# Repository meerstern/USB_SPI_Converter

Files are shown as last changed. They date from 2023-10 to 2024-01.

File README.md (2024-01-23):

# USB-SPI変換基板
USB SPI Converter with MCP2210
## 概要
  * USBをSPIマスタに変換する基板です
  * デバイスの動作確認やラピッドプロトタイピングに最適です
  * [MCP2210][1]を用いたUSB-SPI変換アダプタです
  * PMOD互換コネクタを搭載しており、SPIデバイスに簡単に接続可能です
  * VCC/信号電圧はスイッチ切替で5V/3.3V切替に対応しています  
    ※3.3V専用デバイスに5Vを加えないように注意してください
    
## 詳細
 *  MCP2210はHID標準デバイスとして認識されるため、ドライバは不要です
 *  MCP2210の仕様についてはデータシートを参照してください
 *  9つのGPIO及び1つのSPIポートが利用可能です
 *  SPIクロック速度は1.5k~ 12Mbpsまで対応しています
 *  全SPIモード(Mode 0, 1, 2, 3)に対応しています
 *  64byteの送受信バッファを搭載しています
 *  1回の送受信は最大65535byteまで対応しています
 *  HIDデバイスとして認識される仕様上、最大転送レートは64kByte/sec程度となります  
 *  COM-LEDはIO3に接続されています
 *  基板上のSPI Flashパターンを介して書き込む場合はIO0とIO2をhighに設定してください  
 *  USB5V電源入力側に350mA定格のリセッタブルヒューズを搭載しています  
 *  給電可能な電流は3.3Vラインで最大150mA前後、5Vラインで最大350mAです  

## サンプル例
 * MCP2210 Utility  
 [Microchip社MCP2210 Utility][2]からGUIでSPI通信をすることが可能です
 * Web USB SPI  
 Web USB HID APIを用いた[ツールでブラウザから操作するアプリ][3]です。オフラインでも動作可能です。
 * Web USB SPI Flash Tool  
 Web USB HID APIを用いた[ツールでブラウザからSPI Flashの読込/書込するアプリ][4]です。オフラインでも動作可能です。

## ピンアサイン
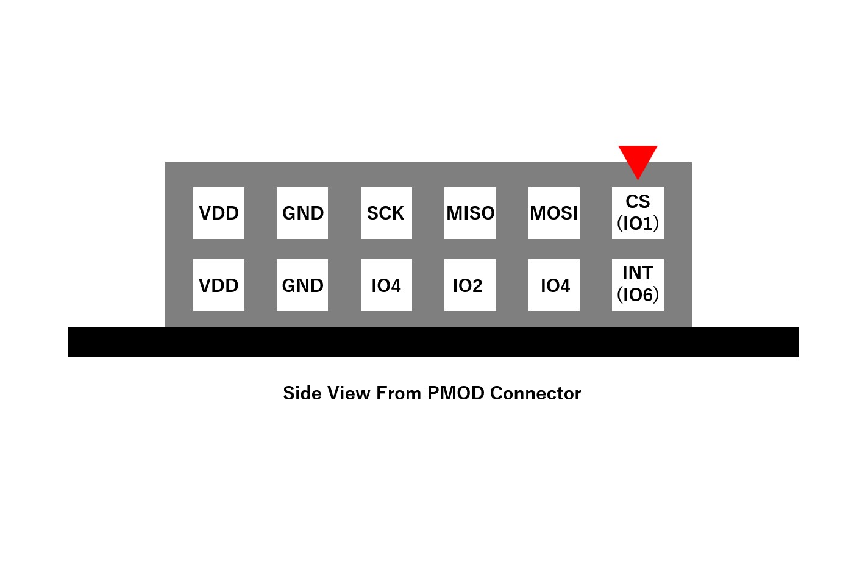
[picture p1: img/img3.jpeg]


## 外観
 * 基板サイズ45mm x 25mm(突起部除く)
 * 固定穴M3x2、幅19mm 
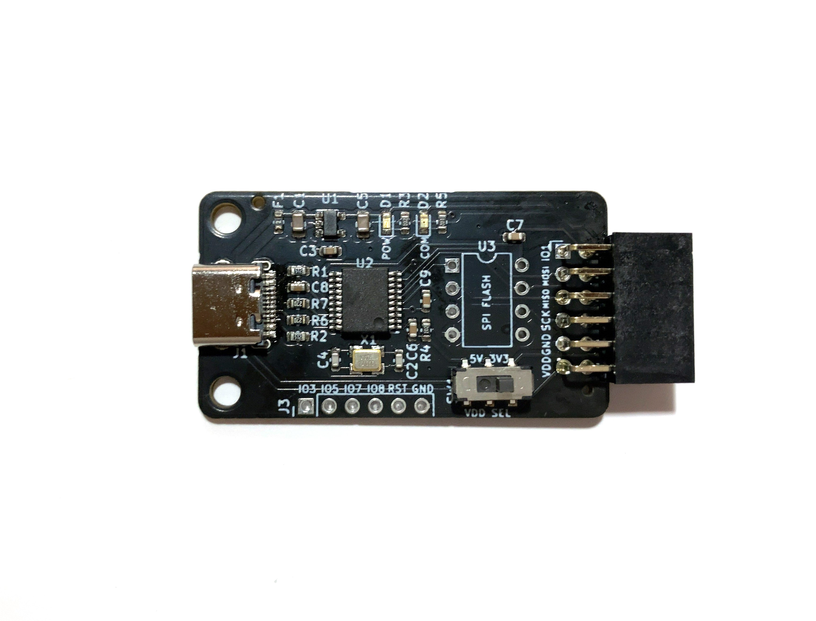
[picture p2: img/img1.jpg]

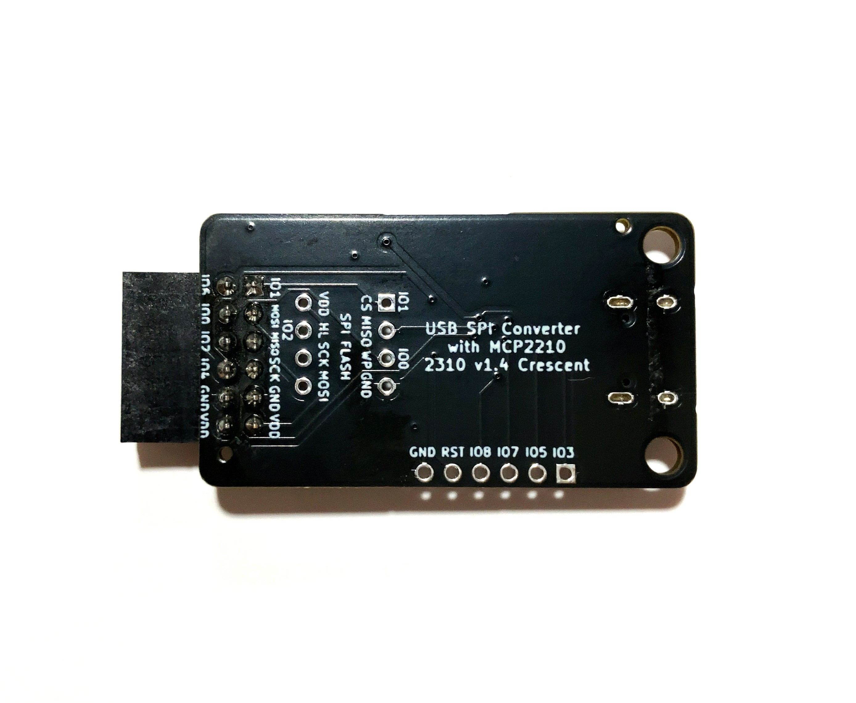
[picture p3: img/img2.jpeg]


## 販売サイト
  * [スイッチサイエンス][5]

[1]: https://www.microchip.com/en-us/product/MCP2210
[2]: https://ww1.microchip.com/downloads/en/DeviceDoc/MCP2210Utility-v1.2.3-windows-installer.zip
[3]: https://meerstern.github.io/web_usb_spi.html
[4]: https://meerstern.github.io/web_spi_flash_tool.html
[5]: https://ssci.to/9394

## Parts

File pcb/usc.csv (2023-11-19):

ID | 参照記号 | パッケージ | 数 | 名称 | Supplier and ref
1 | SW1 | DPDT_SMD | 1 | SW_DPDT_x2
2 | U3 | DIP-8_W7.62mm | 1 | SPI Flash
3 | J3 | PinHeader_1x06_P2.54mm_Vertical | 1 | Conn_01x06
4 | C9,C7,C6 | C_0603_1608Metric | 3 | 0.1u
5 | C8 | C_0603_1608Metric | 1 | 2.2u
6 | REF2,REF1 | MountingHole_3.2mm_M3 | 2 | MountingHole_3.2mm_M3
7 | X1 | FA238V | 1 | 12MHz
8 | U2 | TSSOP-20_4.4x6.5mm_P0.65mm | 1 | MCP2210
9 | U1 | SOT-23-5 | 1 | LD3985M33R_SOT23
10 | R7,R6 | R_0603_1608Metric | 2 | 33
11 | R5,R4,R3 | R_0603_1608Metric | 3 | 1k
12 | R2,R1 | R_0603_1608Metric | 2 | 5.1k
13 | J2 | PMOD | 1 | PMOD
14 | J1 | TypeC_16Pin | 1 | TypeC16Pin
15 | F1 | Fuse_0603_1608Metric | 1 | 300mA
16 | D2 | D_0603_1608Metric | 1 | Red LED
17 | D1 | D_0603_1608Metric | 1 | Blue LED
18 | C5,C1 | C_0805_2012Metric | 2 | 10u
19 | C4,C2 | C_0603_1608Metric | 2 | 10p
20 | C3 | C_0603_1608Metric | 1 | 0.01u

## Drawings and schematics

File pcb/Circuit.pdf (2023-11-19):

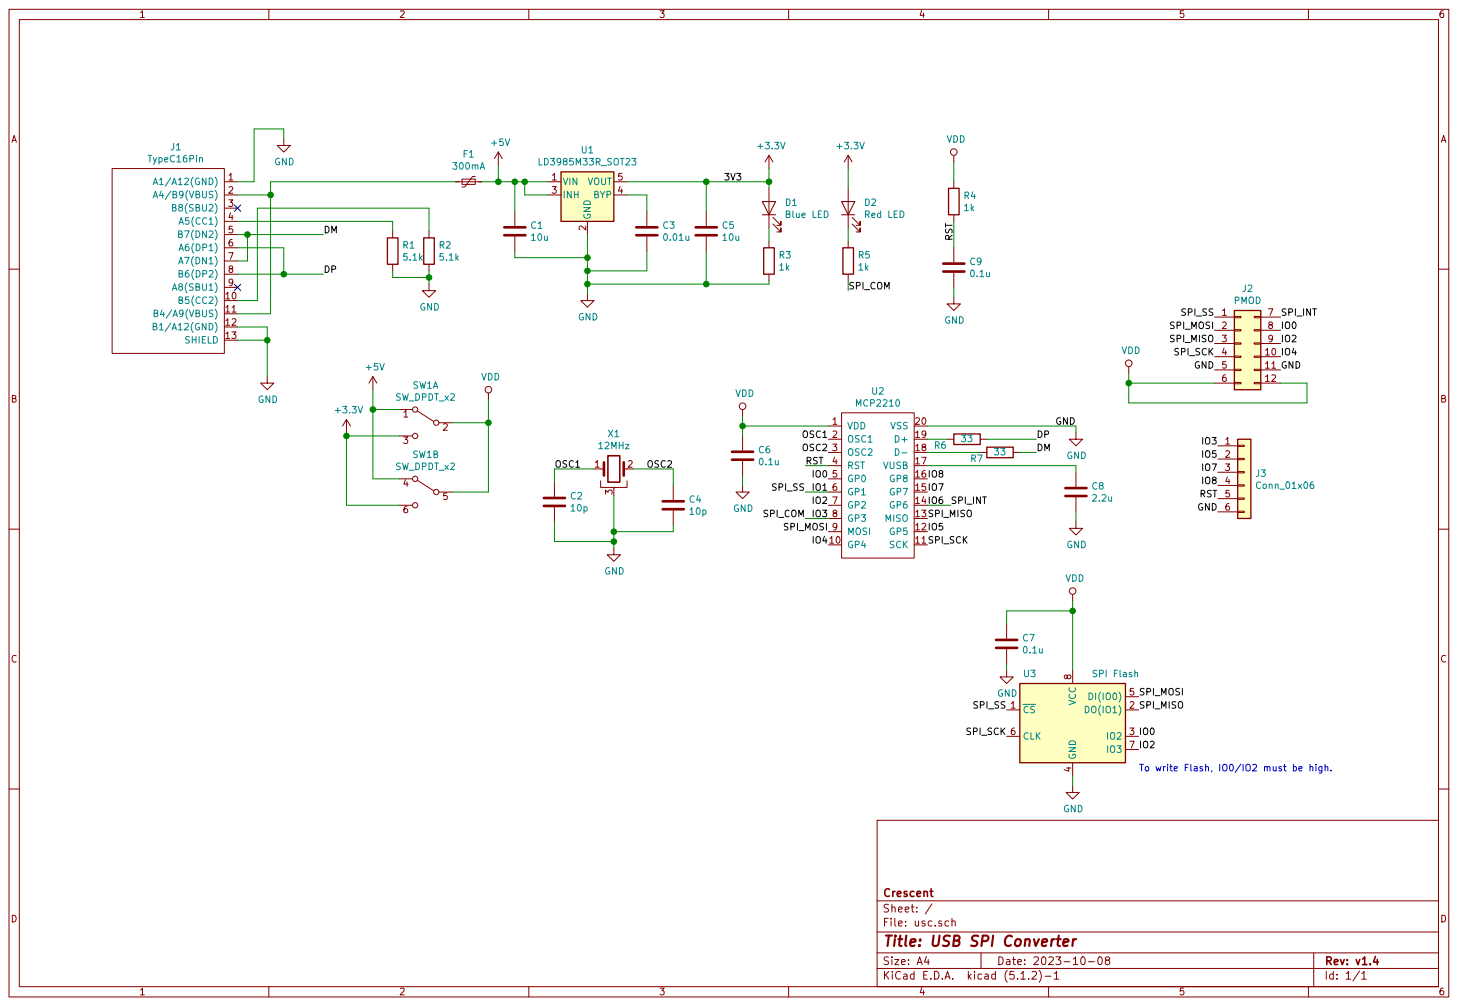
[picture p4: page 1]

1k D2Red LED
To write Flash, IO0/IO2 must be high. 1

Id: 1/1 Title: USB SPI Converter File: usc.sch Sheet: / Crescent

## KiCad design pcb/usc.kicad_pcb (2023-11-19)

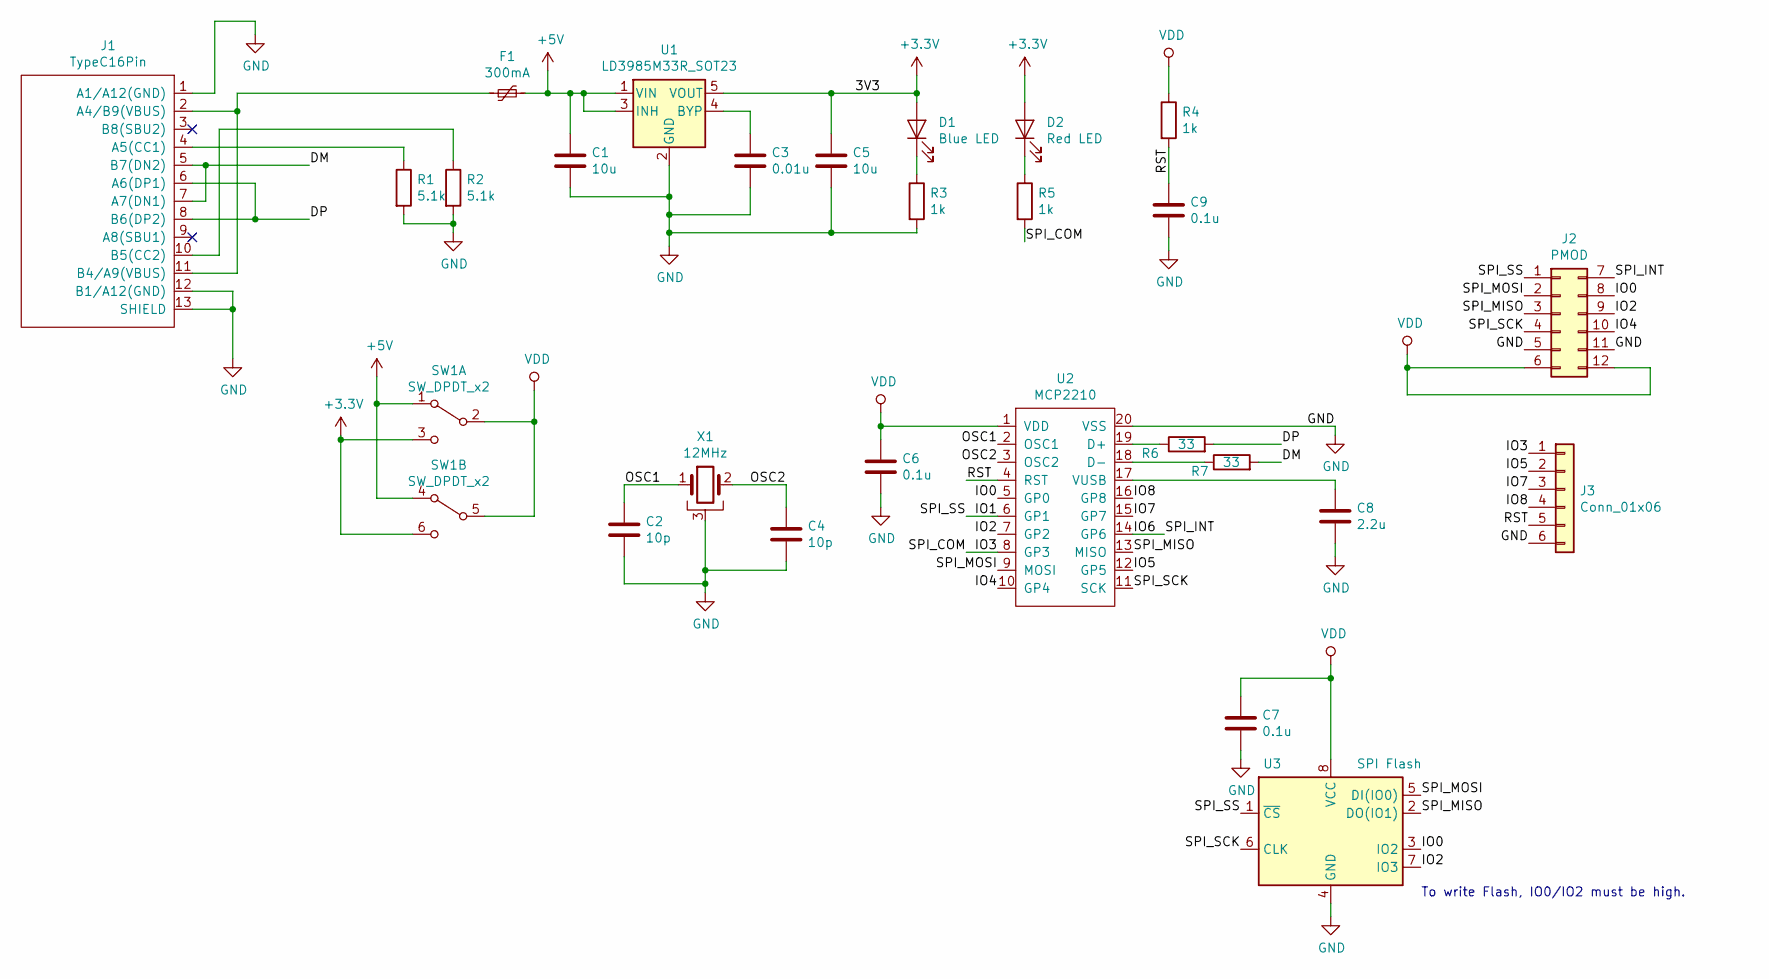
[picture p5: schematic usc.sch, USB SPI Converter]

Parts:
C1, C5: 10u; C_0805_2012Metric
C2, C4: 10p; C_0603_1608Metric
C3: 0.01u; C_0603_1608Metric
C6, C7, C9: 0.1u; C_0603_1608Metric
C8: 2.2u; C_0603_1608Metric
D1: Blue LED; D_0603_1608Metric
D2: Red LED; D_0603_1608Metric
F1: 300mA; Fuse_0603_1608Metric
J1: TypeC16Pin; TypeC_16Pin
J2: PMOD
J3: Conn_01x06; PinHeader_1x06_P2.54mm_Vertical
R1, R2: 5.1k; R_0603_1608Metric
R3, R4, R5: 1k; R_0603_1608Metric
R6, R7: 33; R_0603_1608Metric
SW1: SW_DPDT_x2; DPDT_SMD
U1: LD3985M33R_SOT23; SOT-23-5
U2: MCP2210; TSSOP-20_4.4x6.5mm_P0.65mm
U3: SPI Flash; DIP-8_W7.62mm
X1: 12MHz; FA238V

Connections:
+3V3: C5.1, D1.2 (A), D2.2 (A), SW1.3 (C), SW1.6 (C), U1.5 (VOUT)
+5V: C1.1, F1.2, SW1.1 (A), SW1.4 (A), U1.1 (VIN), U1.3 (INH)
/DM: J1.5 (B7(DN2)), J1.7 (A7(DN1)), R7.2
/DP: J1.6 (A6(DP1)), J1.8 (B6(DP2)), R6.2
/IO0: J2.8, U2.5 (GP0), U3.3 (IO2)
/IO1: J2.1, U2.6 (GP1), U3.1 (~CS)
/IO2: J2.9, U2.7 (GP2), U3.7 (IO3)
/IO3: J3.1, R5.2, U2.8 (GP3)
/IO4: J2.10, U2.10 (GP4)
/IO5: J3.2, U2.12 (GP5)
/IO6: J2.7, U2.14 (GP6)
/IO7: J3.3, U2.15 (GP7)
/IO8: J3.4, U2.16 (GP8)
/OSC1: C2.1, U2.2 (OSC1), X1.1
/OSC2: C4.1, U2.3 (OSC2), X1.2
/RST: C9.1, J3.5, R4.2, U2.4 (RST)
/SPI_MISO: J2.3, U2.13 (MISO), U3.2 (DO(IO1))
/SPI_MOSI: J2.2, U2.9 (MOSI), U3.5 (DI(IO0))
/SPI_SCK: J2.4, U2.11 (SCK), U3.6 (CLK)
GND: C1.2, C2.2, C3.2, C4.2, C5.2, C6.2, C7.2, C8.2, C9.2, J1.1 (A1/A12(GND)), J1.12 (B1/A12(GND)), J1.13 (SHIELD), J2.5, J2.11, J3.6, R1.2, R2.2, R3.2, U1.2 (GND), U2.20 (VSS), U3.4 (GND), X1.3
unnamed: C3.1, U1.4 (BYP)
unnamed: C8.1, U2.17 (VUSB)
unnamed: D1.1 (K), R3.1
unnamed: D2.1 (K), R5.1
unnamed: F1.1, J1.2 (A4/B9(VBUS)), J1.11 (B4/A9(VBUS))
unnamed: J1.4 (A5(CC1)), R1.1
unnamed: J1.10 (B5(CC2)), R2.1
unnamed: R6.1, U2.19 (D+)
unnamed: R7.1, U2.18 (D-)
VDD: C6.1, C7.1, J2.6, J2.12, R4.1, SW1.2 (B), SW1.5 (B), U2.1 (VDD), U3.8 (VCC)

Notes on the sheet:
To write Flash, IO0/IO2 must be high.

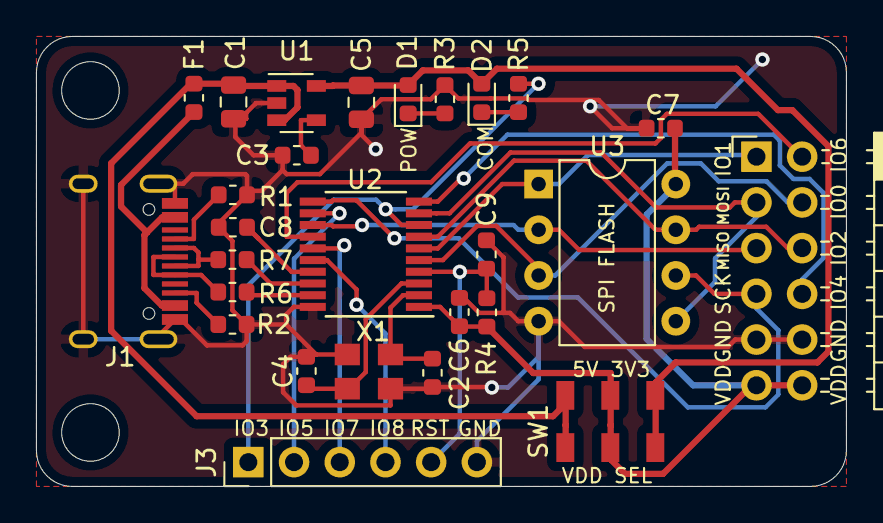
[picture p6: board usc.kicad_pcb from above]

Board: 2 copper layers, 45.0 x 25.0 mm, 29 parts (0 on the bottom side), 30 nets.

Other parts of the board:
REF1, REF2: MountingHole_3.2mm_M3
